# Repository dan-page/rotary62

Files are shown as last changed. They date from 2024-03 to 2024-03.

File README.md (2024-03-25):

# rotary62
ISO 65% Keyboard with Integrated Plate and Rotary Encoder

Includes:
- Case 
- Base
- PCB
- Silicone Sound Dampener
- Encoder Knob
- Rubber Feet

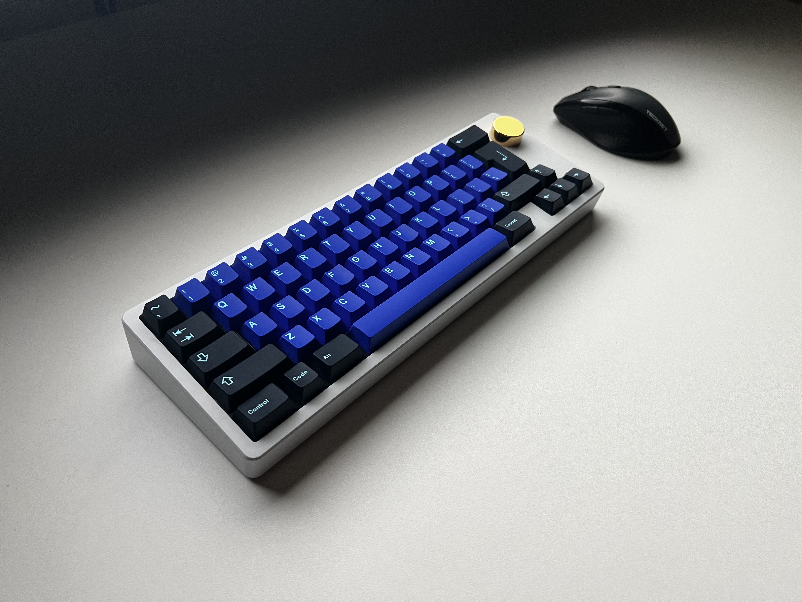
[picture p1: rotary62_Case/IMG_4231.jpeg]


## Case
Machined out of 6063 Aluminium and finished in E-White

## Base
Machined out of 6063 Aluminium and anodised black.

## PCB
The PCB was designed to use common components from JLCPCB. Firmware is available from the [QMK Repo](https://github.com/qmk/qmk_firmware).

## Silicone Sound Dampener
This includes a 3D printable mould that can be filled with silicone to create a sound dampener for inside the case. After 3D printing the two parts of the mould need glueing together and the seam between the two parts making smooth through sanding and filler. 

## Encoder Knob
Machined out of Brass and polished.

## Rubber Feet
Cut from a strip of adhesive-backed 60SH Black Silicone and stuck to the recessed gaps on the base.

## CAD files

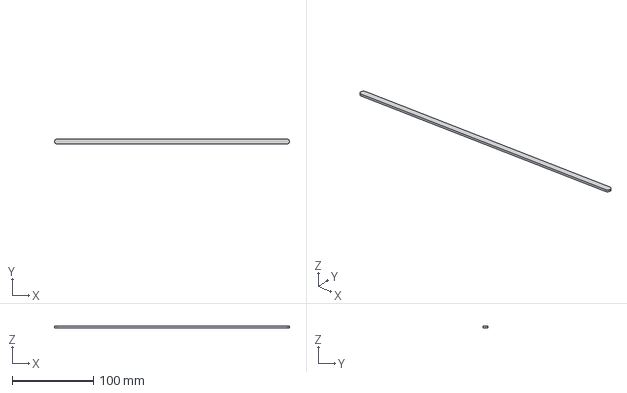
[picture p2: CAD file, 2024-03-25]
rotary62_Case/Rubber Strip.step
289.8 x 6.30 x 2.00 mm

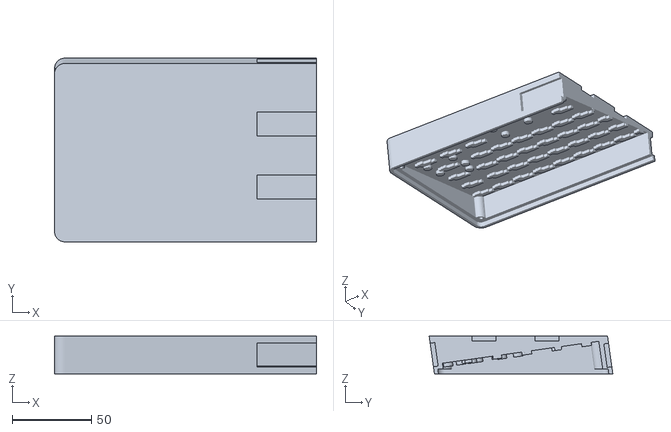
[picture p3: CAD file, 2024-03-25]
rotary62_Dampener/Mold2.stl
165.3 x 115.9 x 23.7

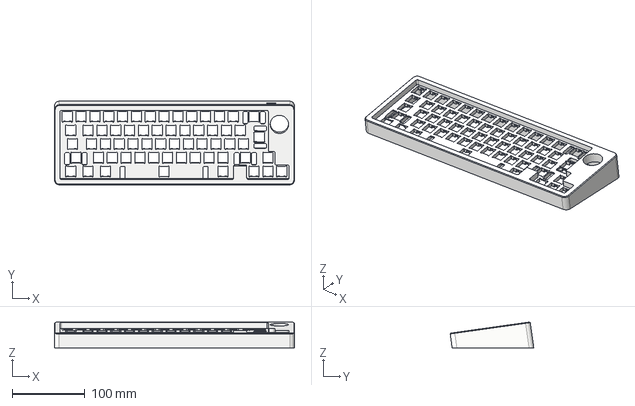
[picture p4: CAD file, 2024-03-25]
rotary62_Case/CaseTop.step
330.5 x 115.2 x 35.7 mm

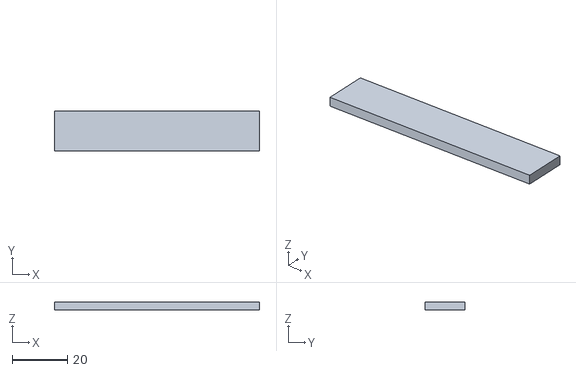
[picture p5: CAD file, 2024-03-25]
rotary62_Dampener/MoldLatch.stl
74.5 x 14.5 x 3.00

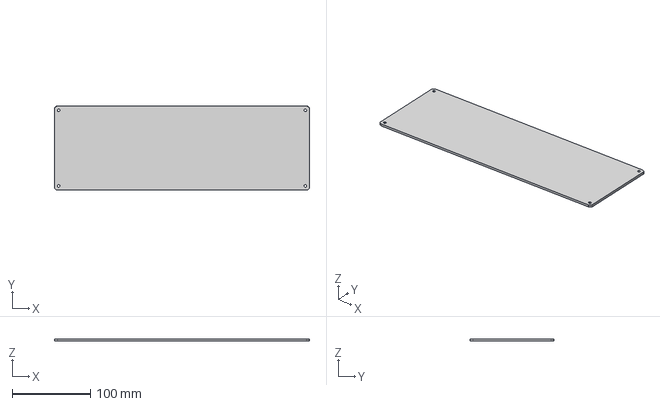
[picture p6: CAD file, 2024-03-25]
rotary62_Case/CaseBase.step
324.9 x 107.3 x 3.13 mm

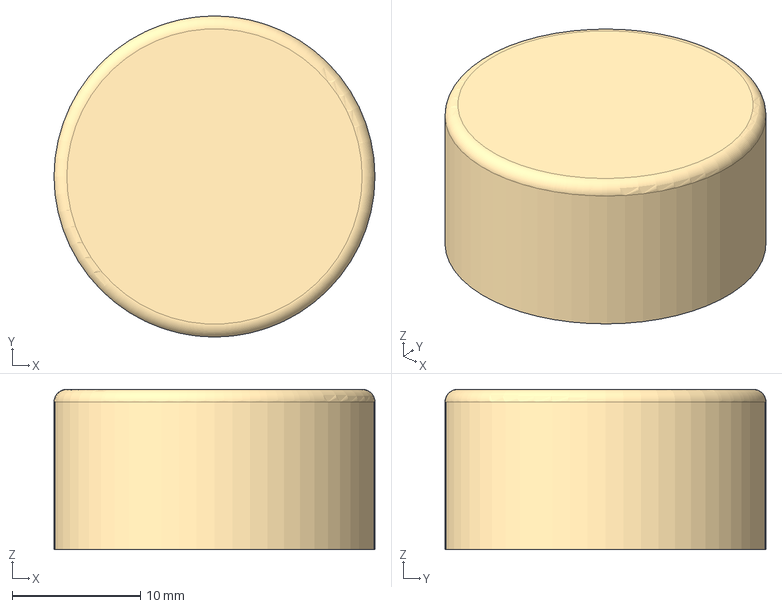
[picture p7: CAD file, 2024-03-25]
rotary62_Case/EncoderKnob.step
25.0 x 25.0 x 12.5 mm

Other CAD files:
rotary62_Dampener/mold1.stl

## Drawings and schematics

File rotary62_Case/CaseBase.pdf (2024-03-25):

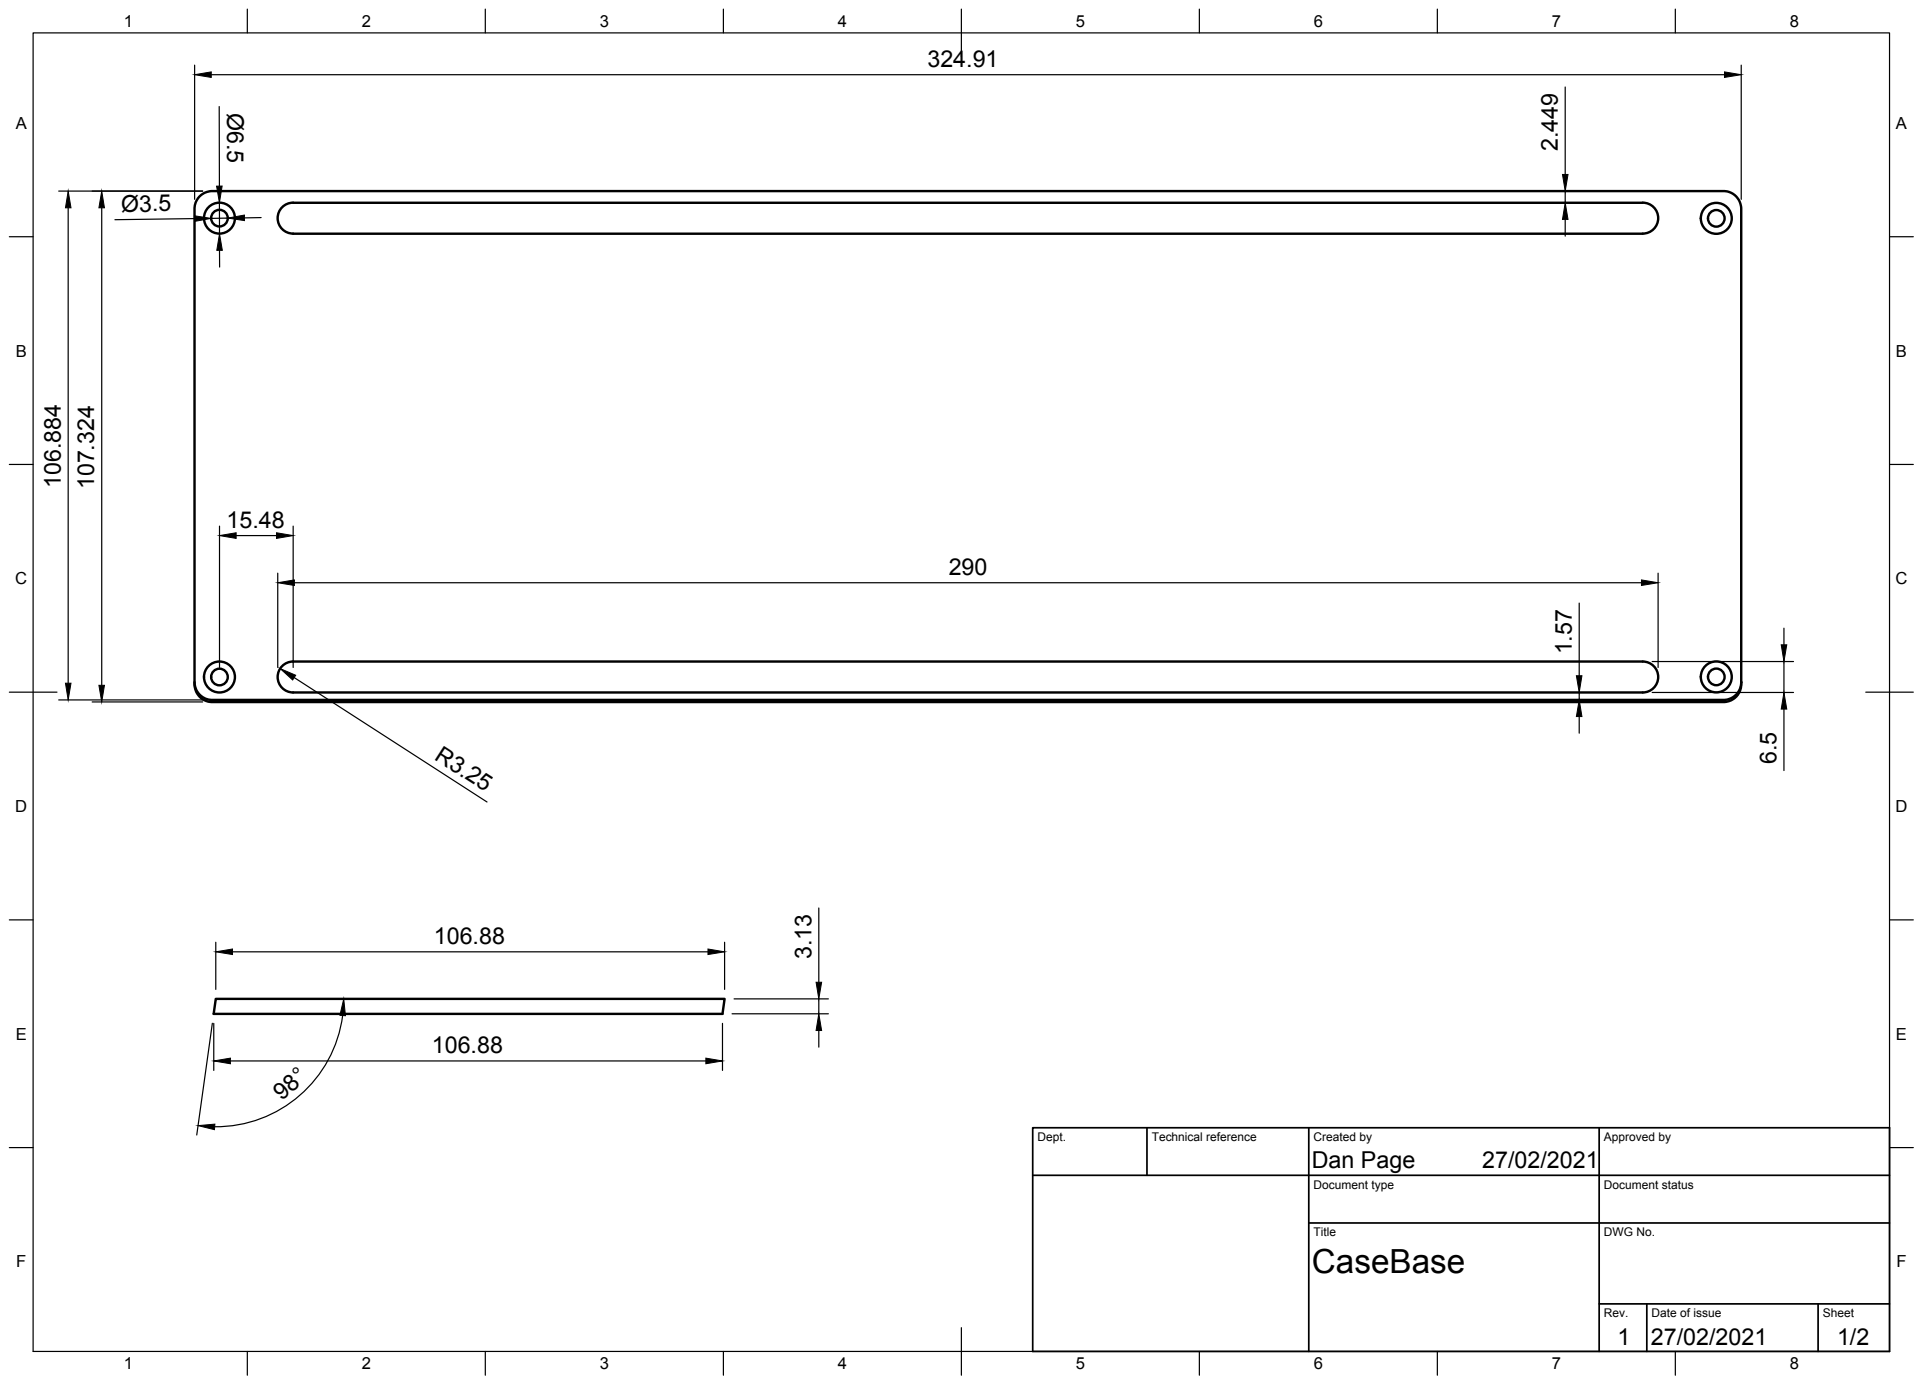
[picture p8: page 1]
Title; DWG No.; Rev.; Date of issue; Sheet

Dept. | Technical reference | Created by Dan Page 27/02/2021 | Approved by

Document type | Document status

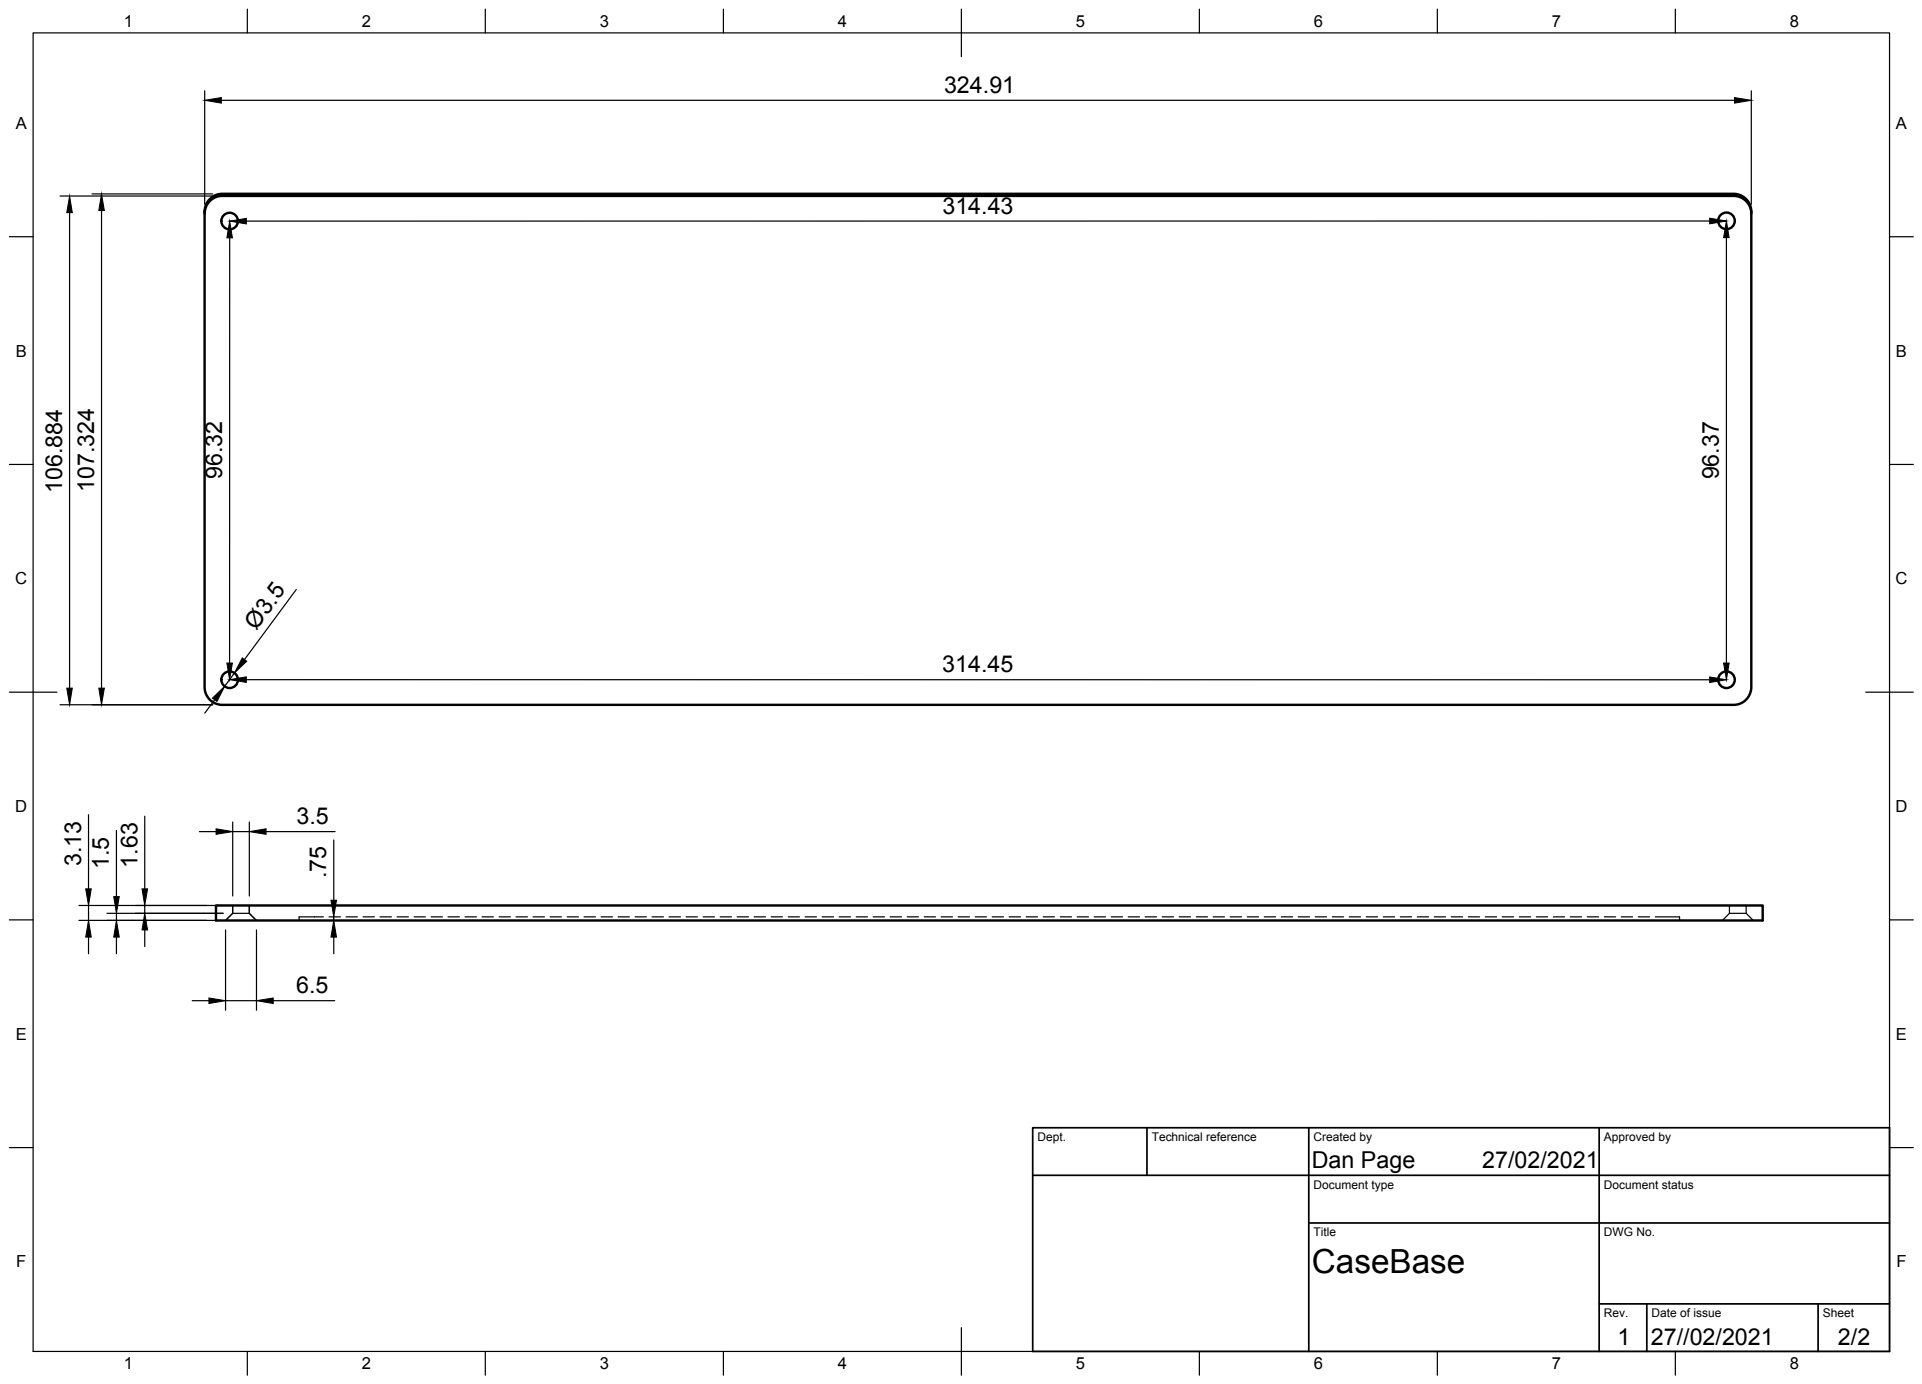
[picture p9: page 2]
Title; DWG No.; Rev.; Date of issue; Sheet

Dept. | Technical reference | Created by Dan Page 27/02/2021 | Approved by

Document type | Document status

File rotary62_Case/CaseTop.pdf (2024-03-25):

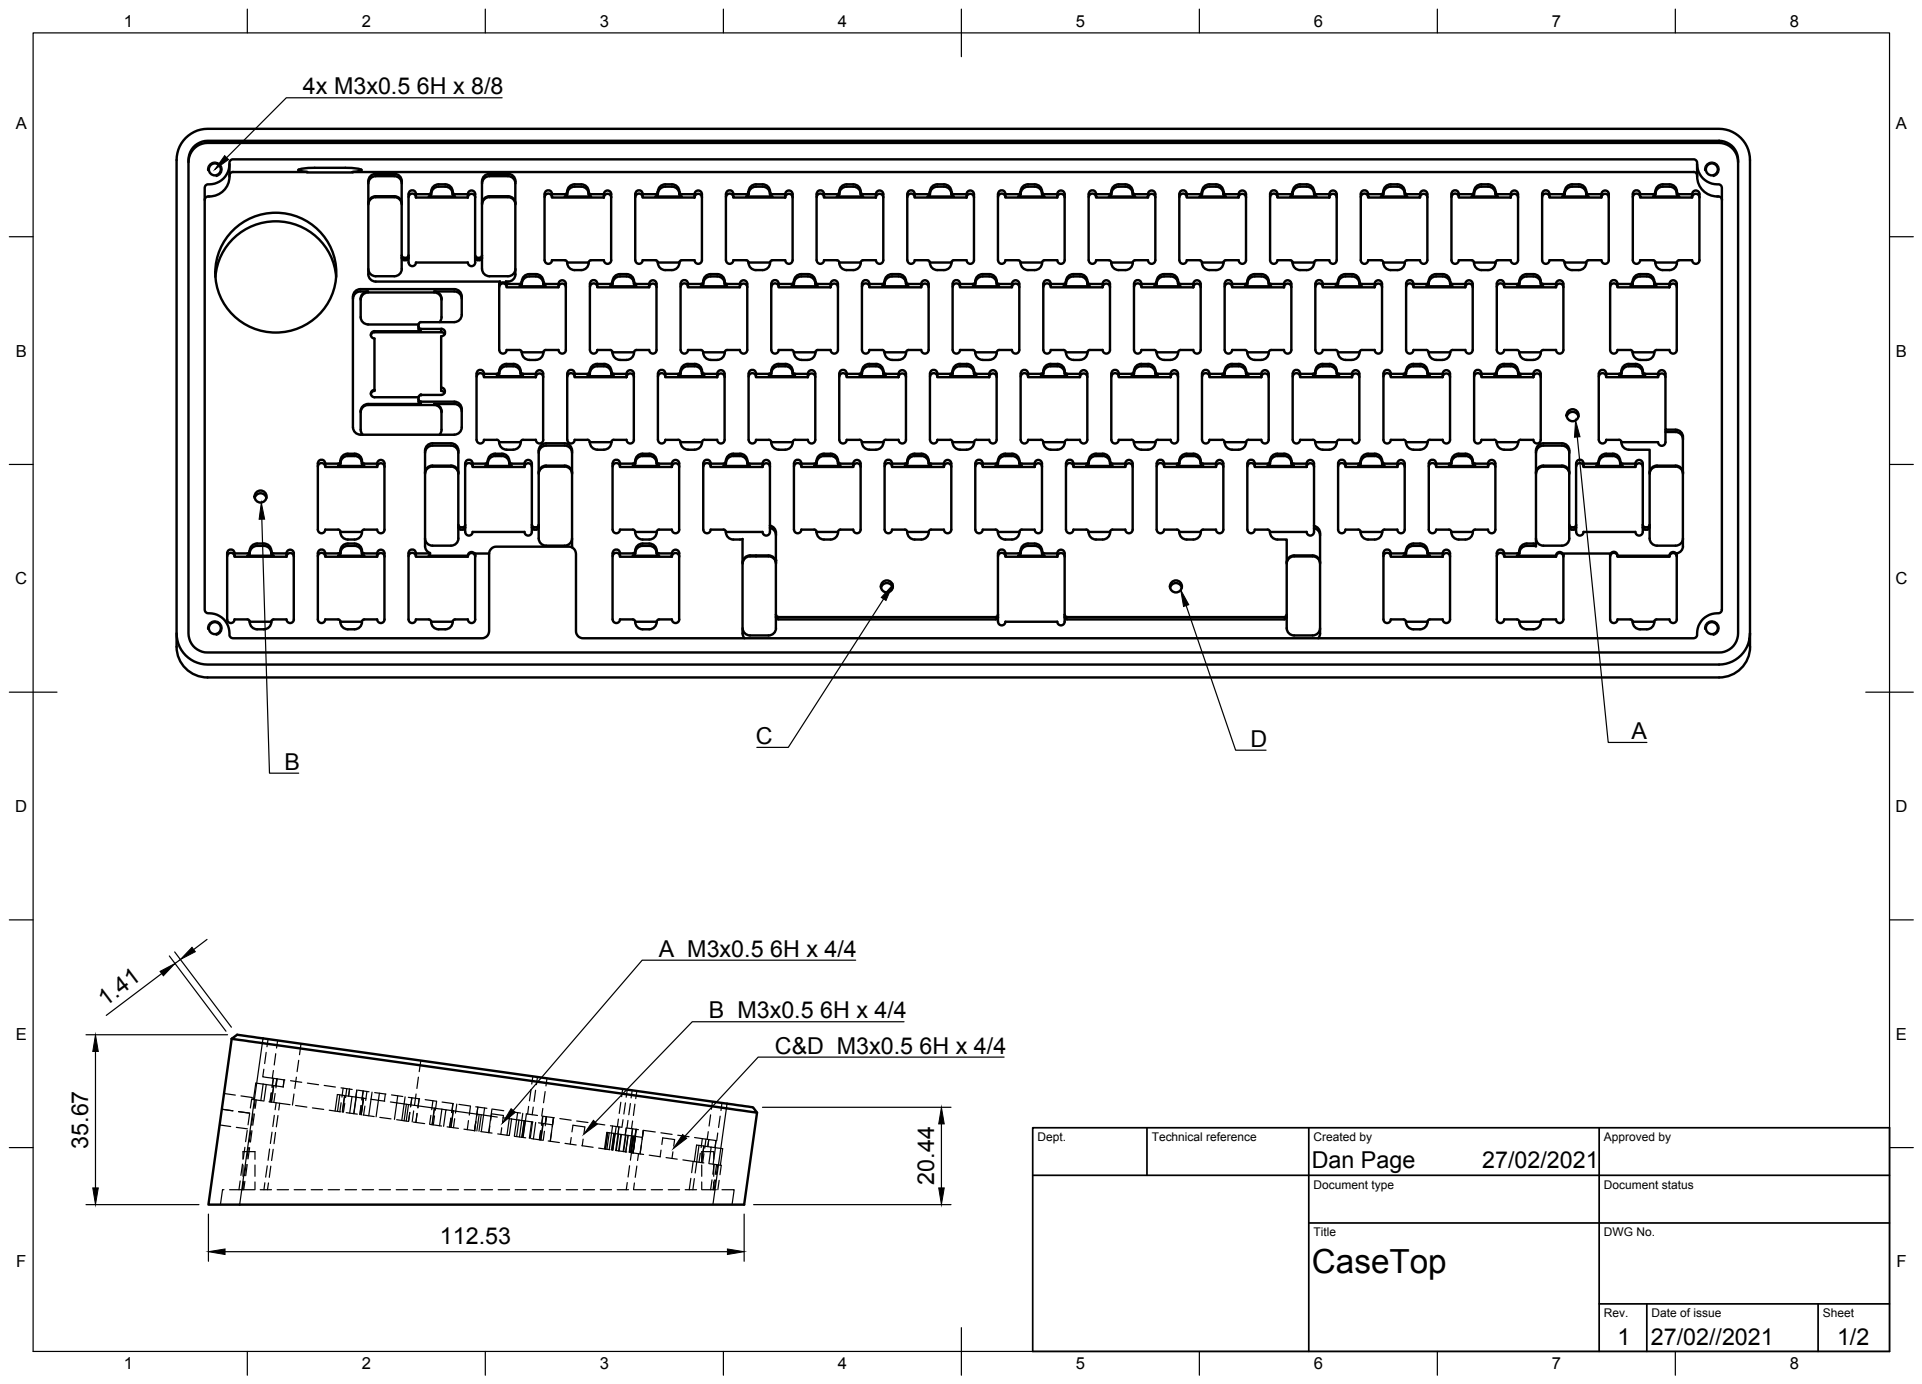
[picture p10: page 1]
Title; DWG No.; Rev.; Date of issue; Sheet

Dept. | Technical reference | Created by Dan Page 27/02/2021 | Approved by

Document type | Document status

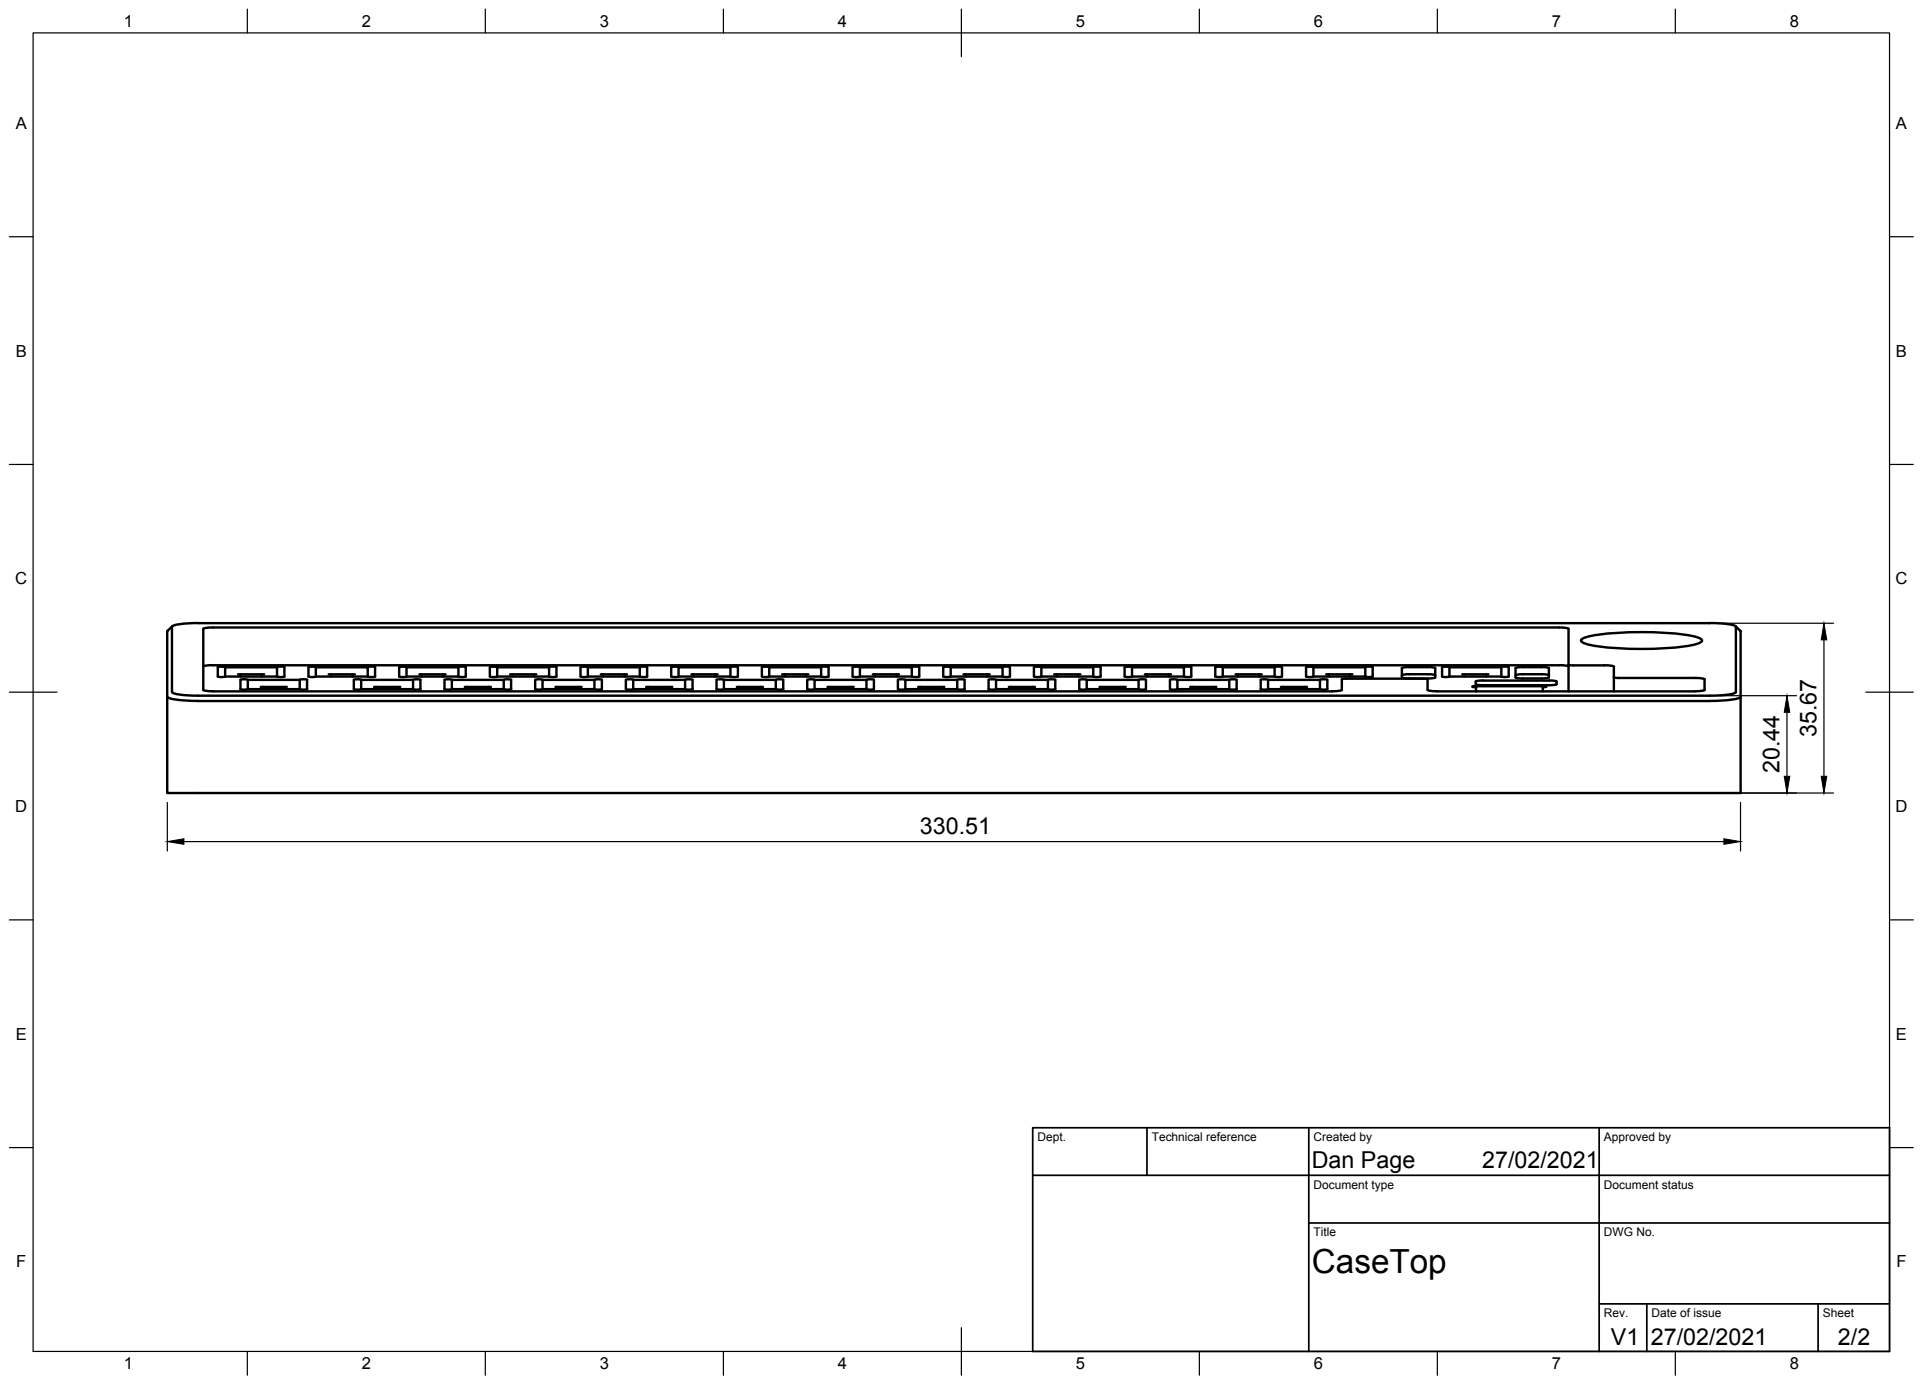
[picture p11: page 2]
Title; DWG No.; Rev.; Date of issue; Sheet; Dan Page

Dept. | Technical reference | Created by 27/02/2021 | Approved by

Document type | Document status

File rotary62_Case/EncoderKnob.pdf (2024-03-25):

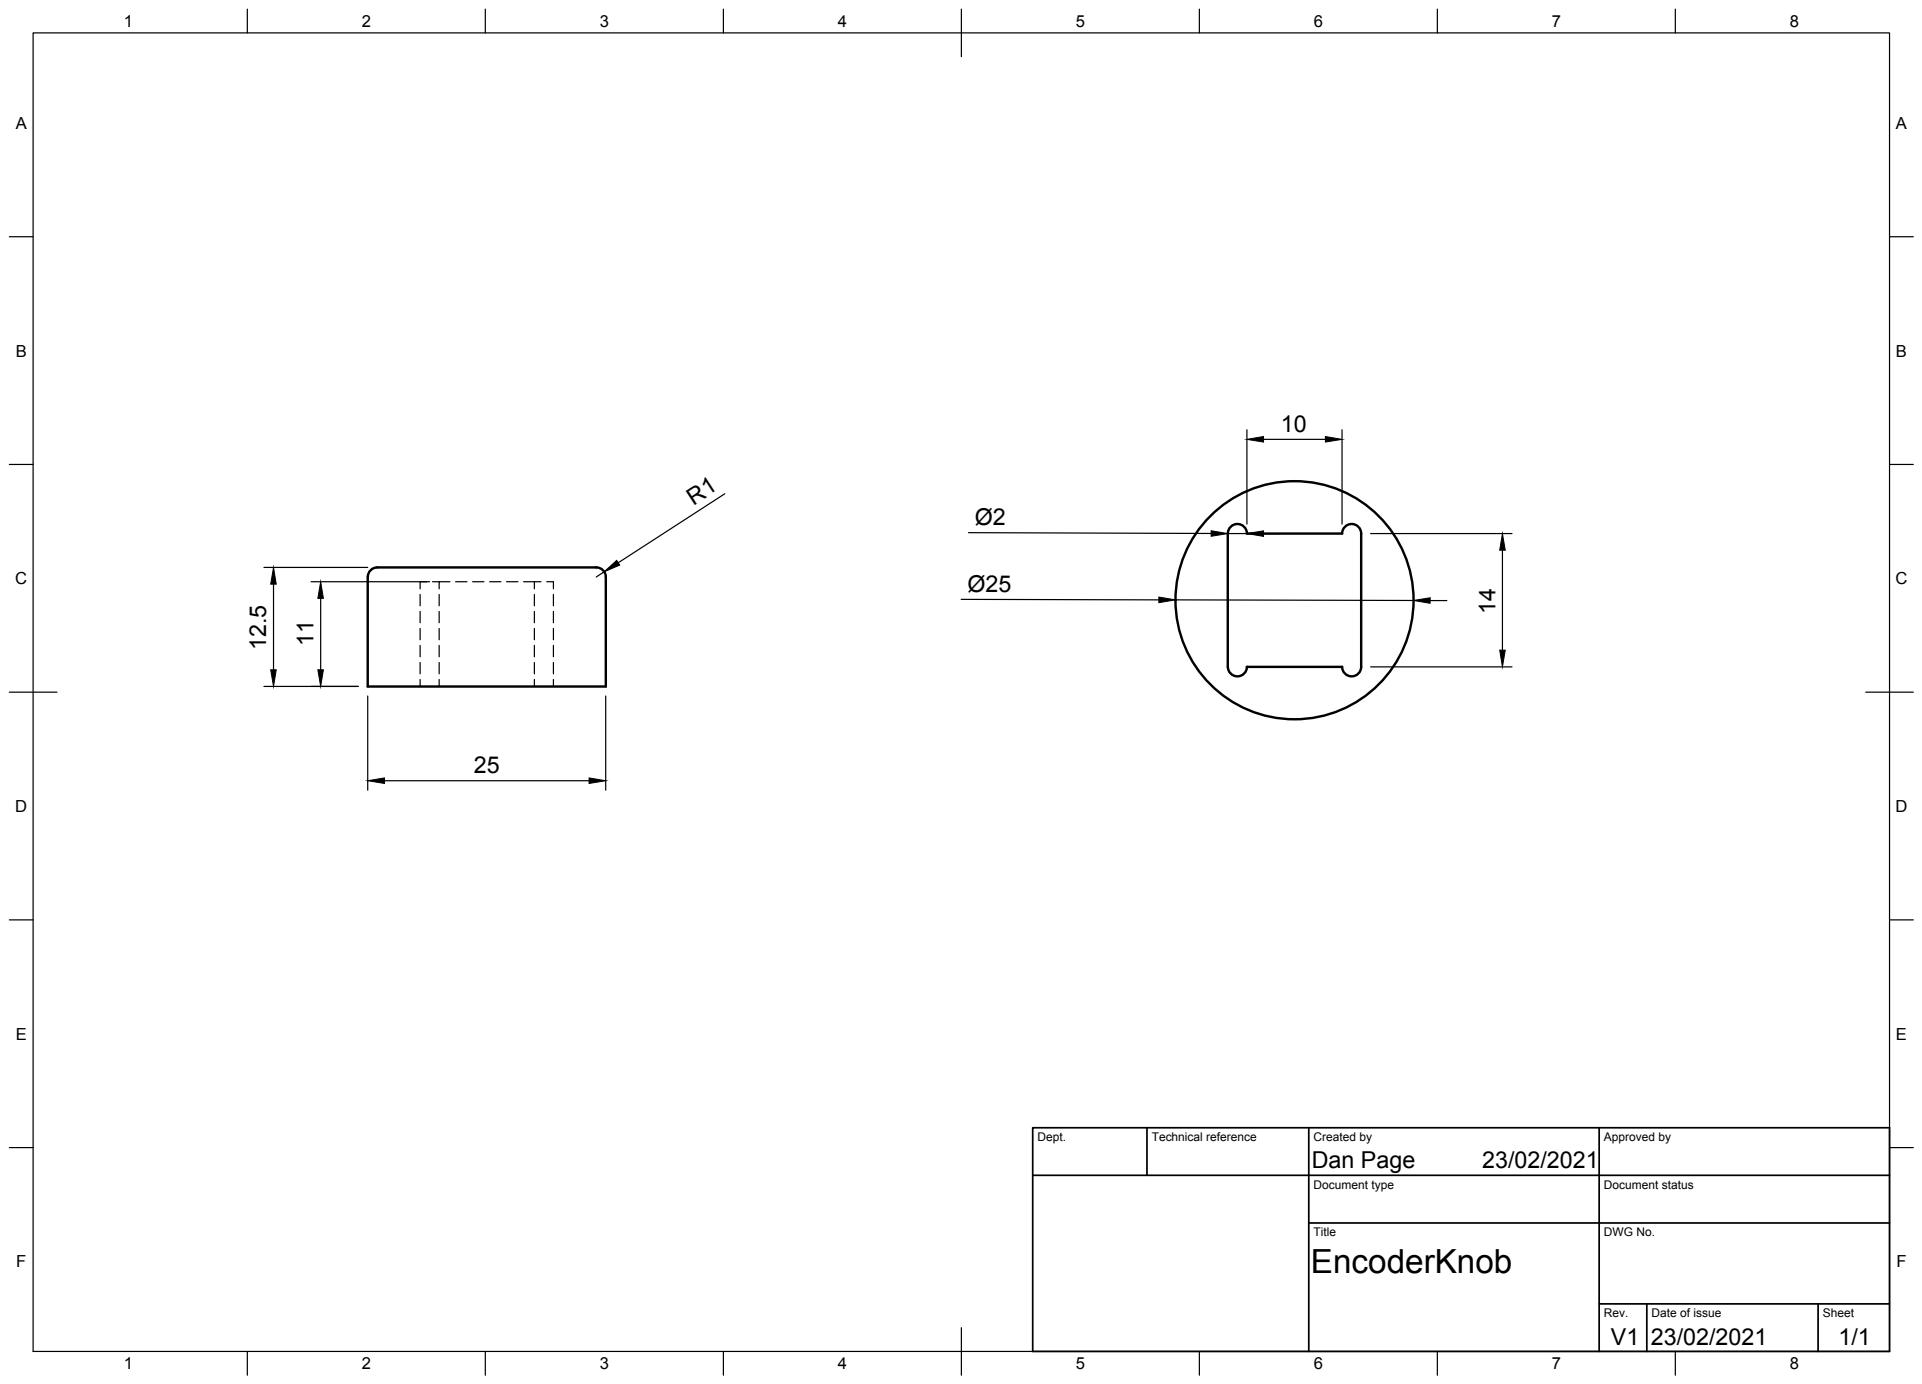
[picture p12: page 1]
Title; DWG No.; Rev.; Date of issue; Sheet; Dan Page 12.5

Dept. | Technical reference | Created by 23/02/2021 | Approved by

Document type | Document status

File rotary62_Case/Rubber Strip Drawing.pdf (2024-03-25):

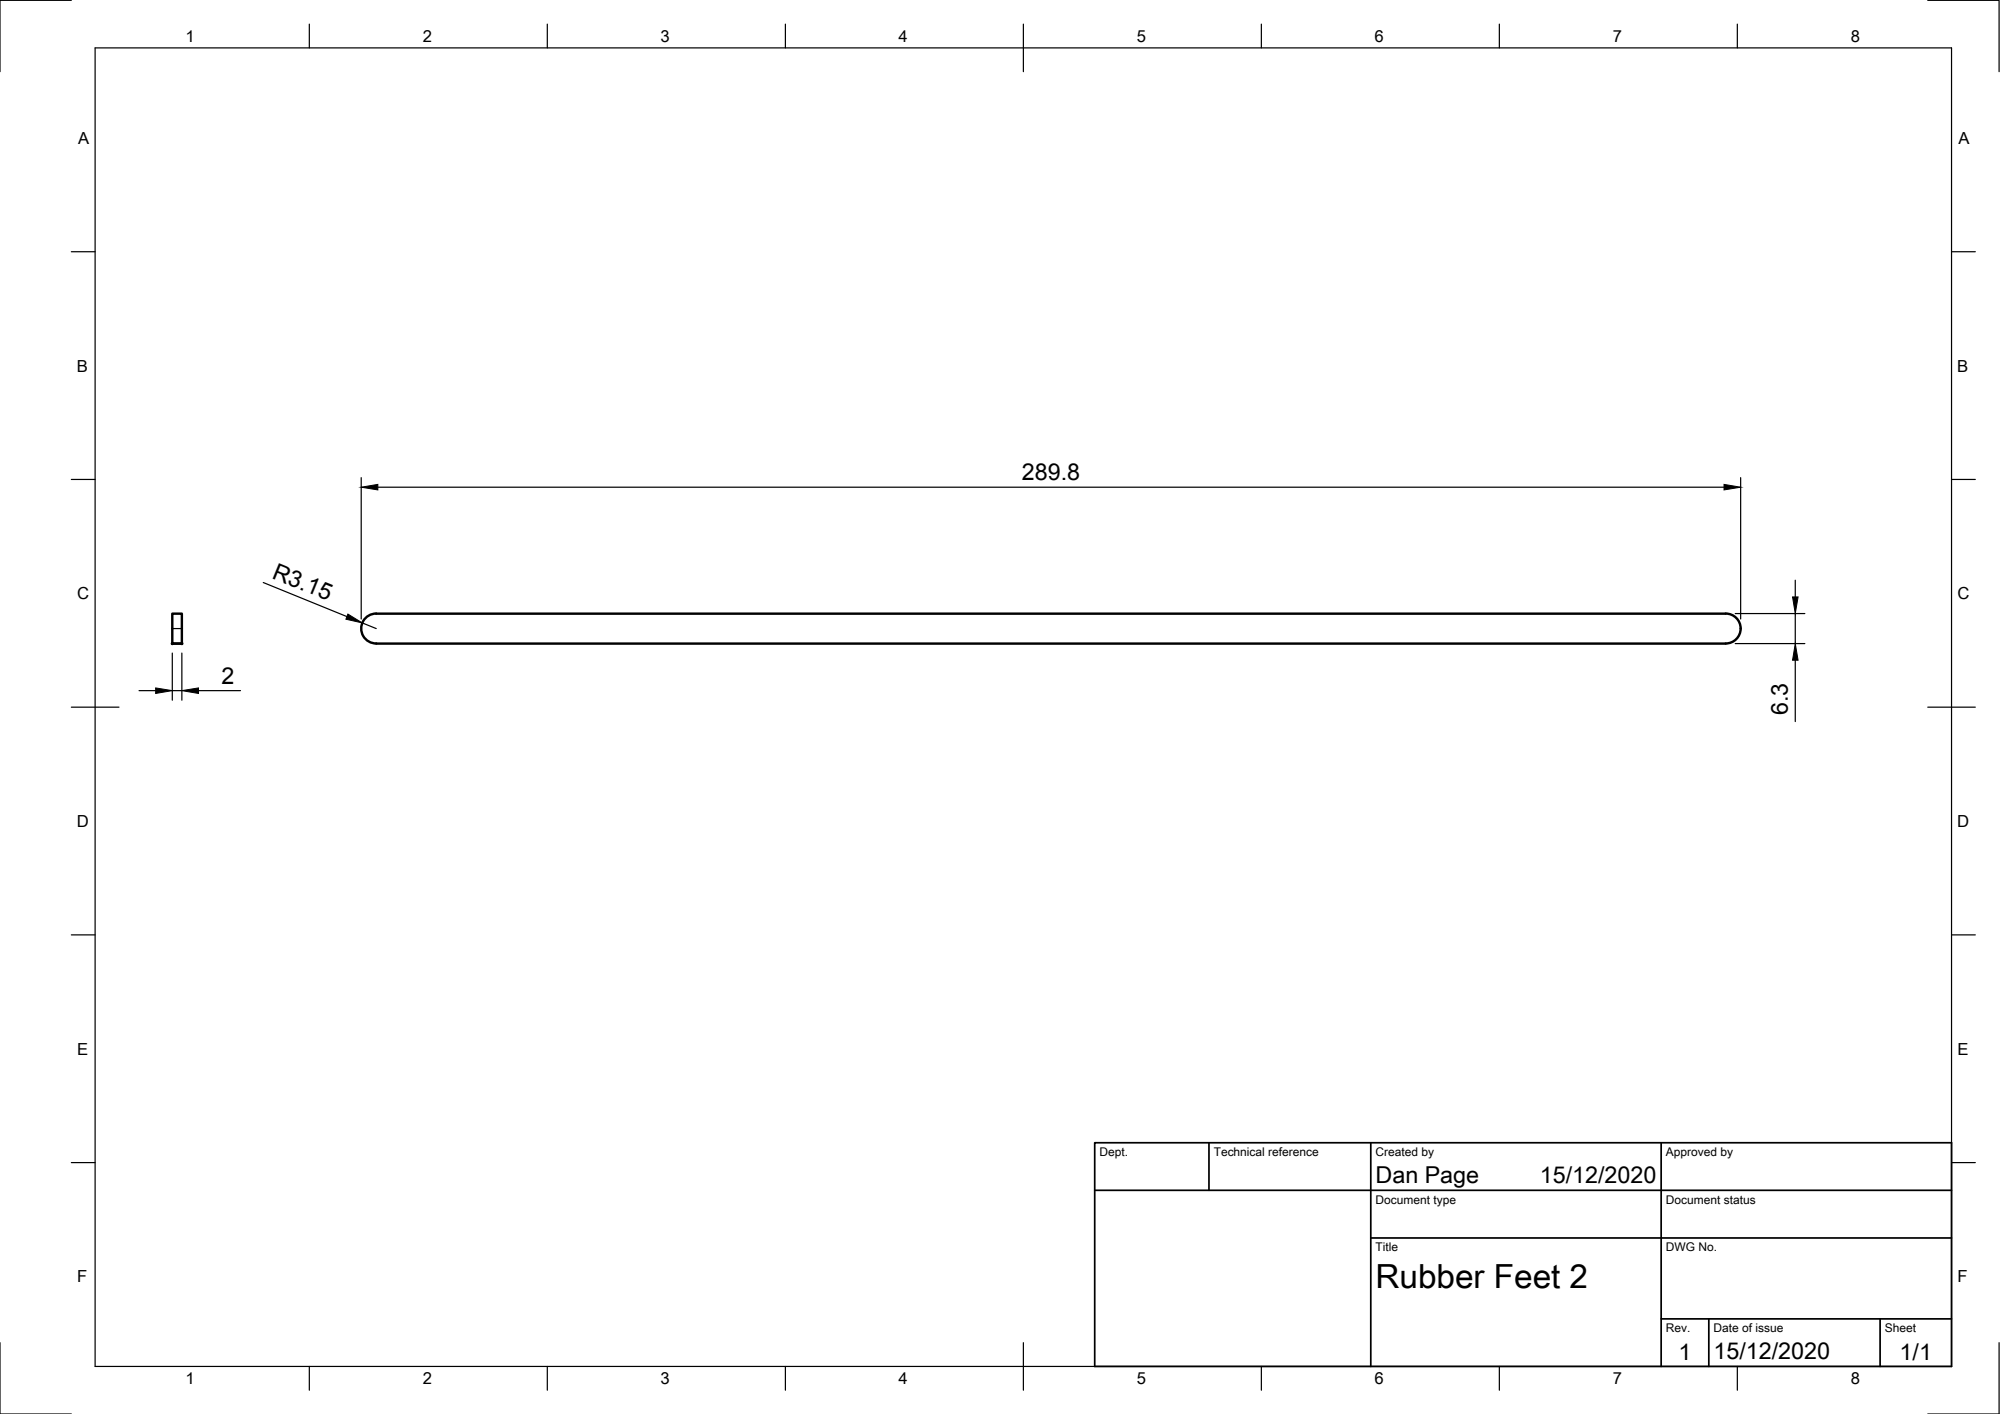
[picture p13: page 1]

Dept. | Technical reference | Created by Dan Page 15/12/2020 | Approved by

Document type | Document status

Title Rubber Feet 2 | DWG No.

Rev. 1 | Date of issue 15/12/2020 | Sheet 1/1

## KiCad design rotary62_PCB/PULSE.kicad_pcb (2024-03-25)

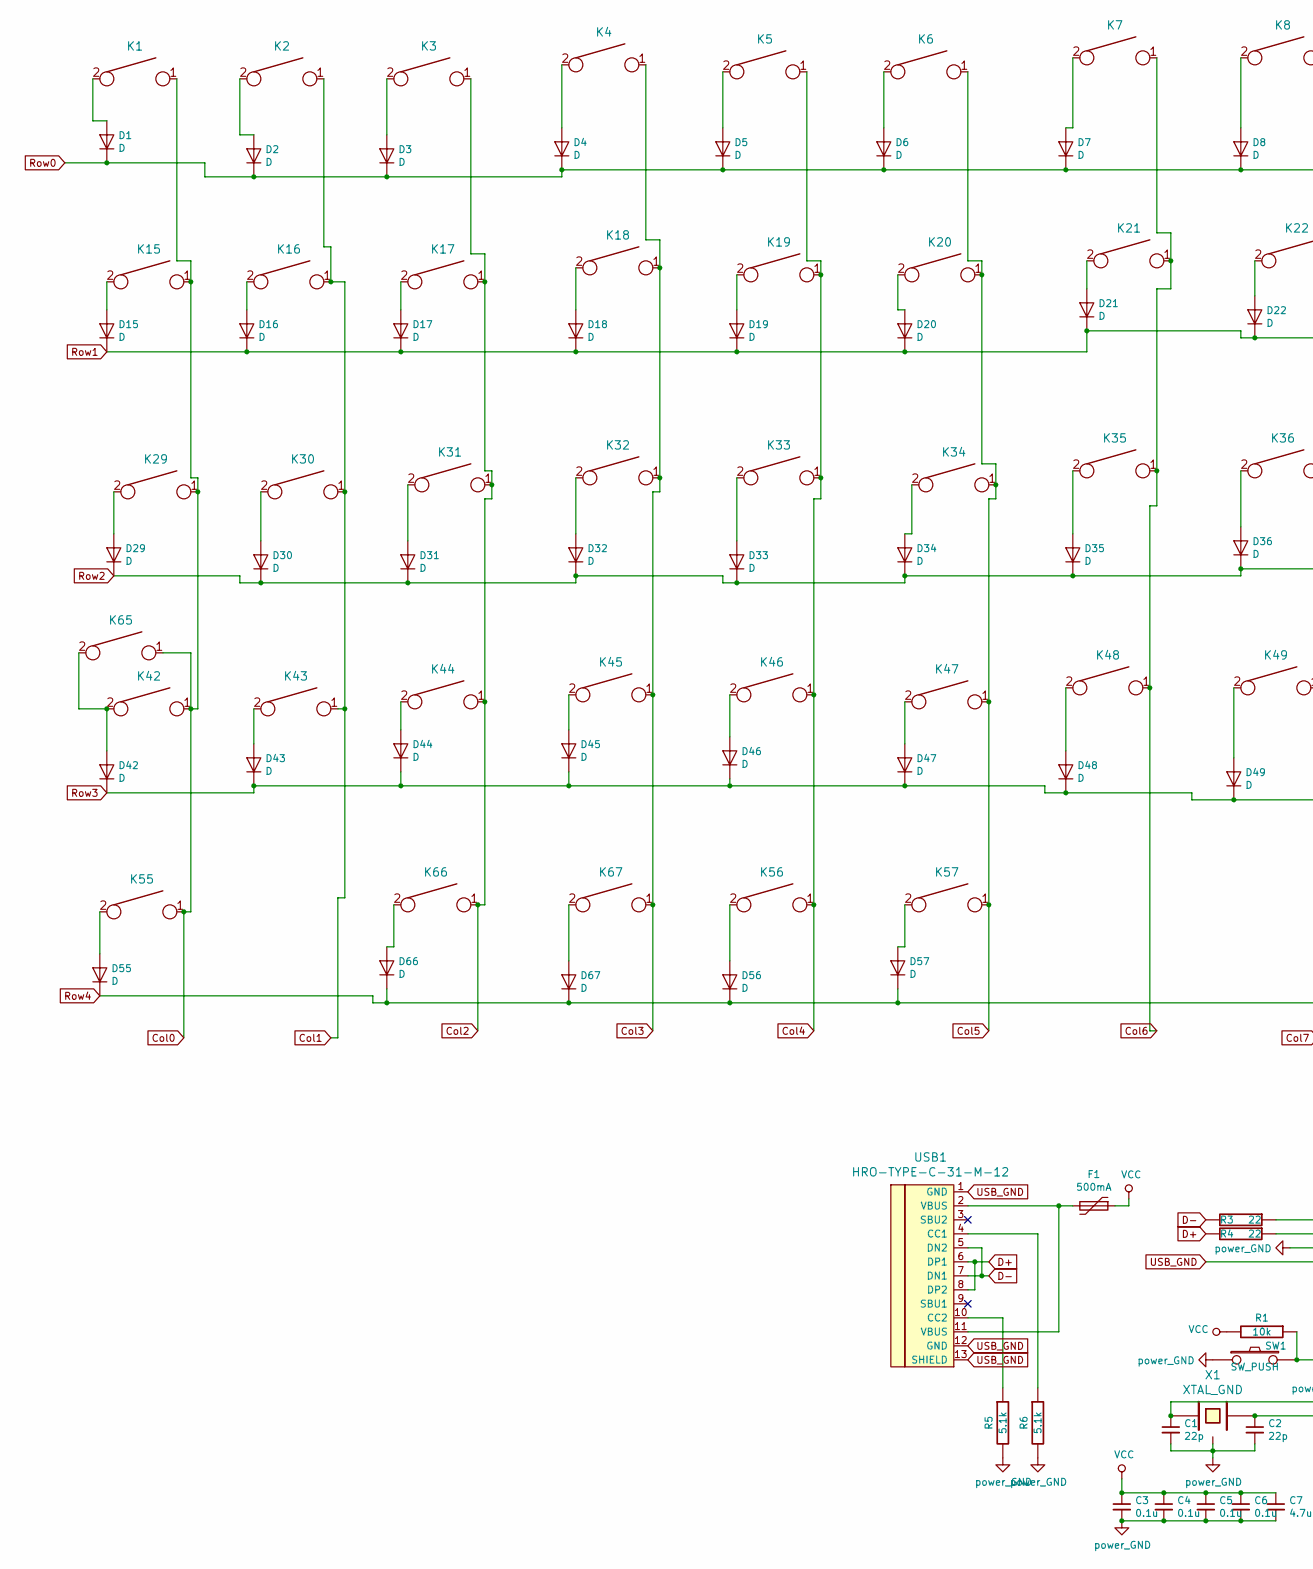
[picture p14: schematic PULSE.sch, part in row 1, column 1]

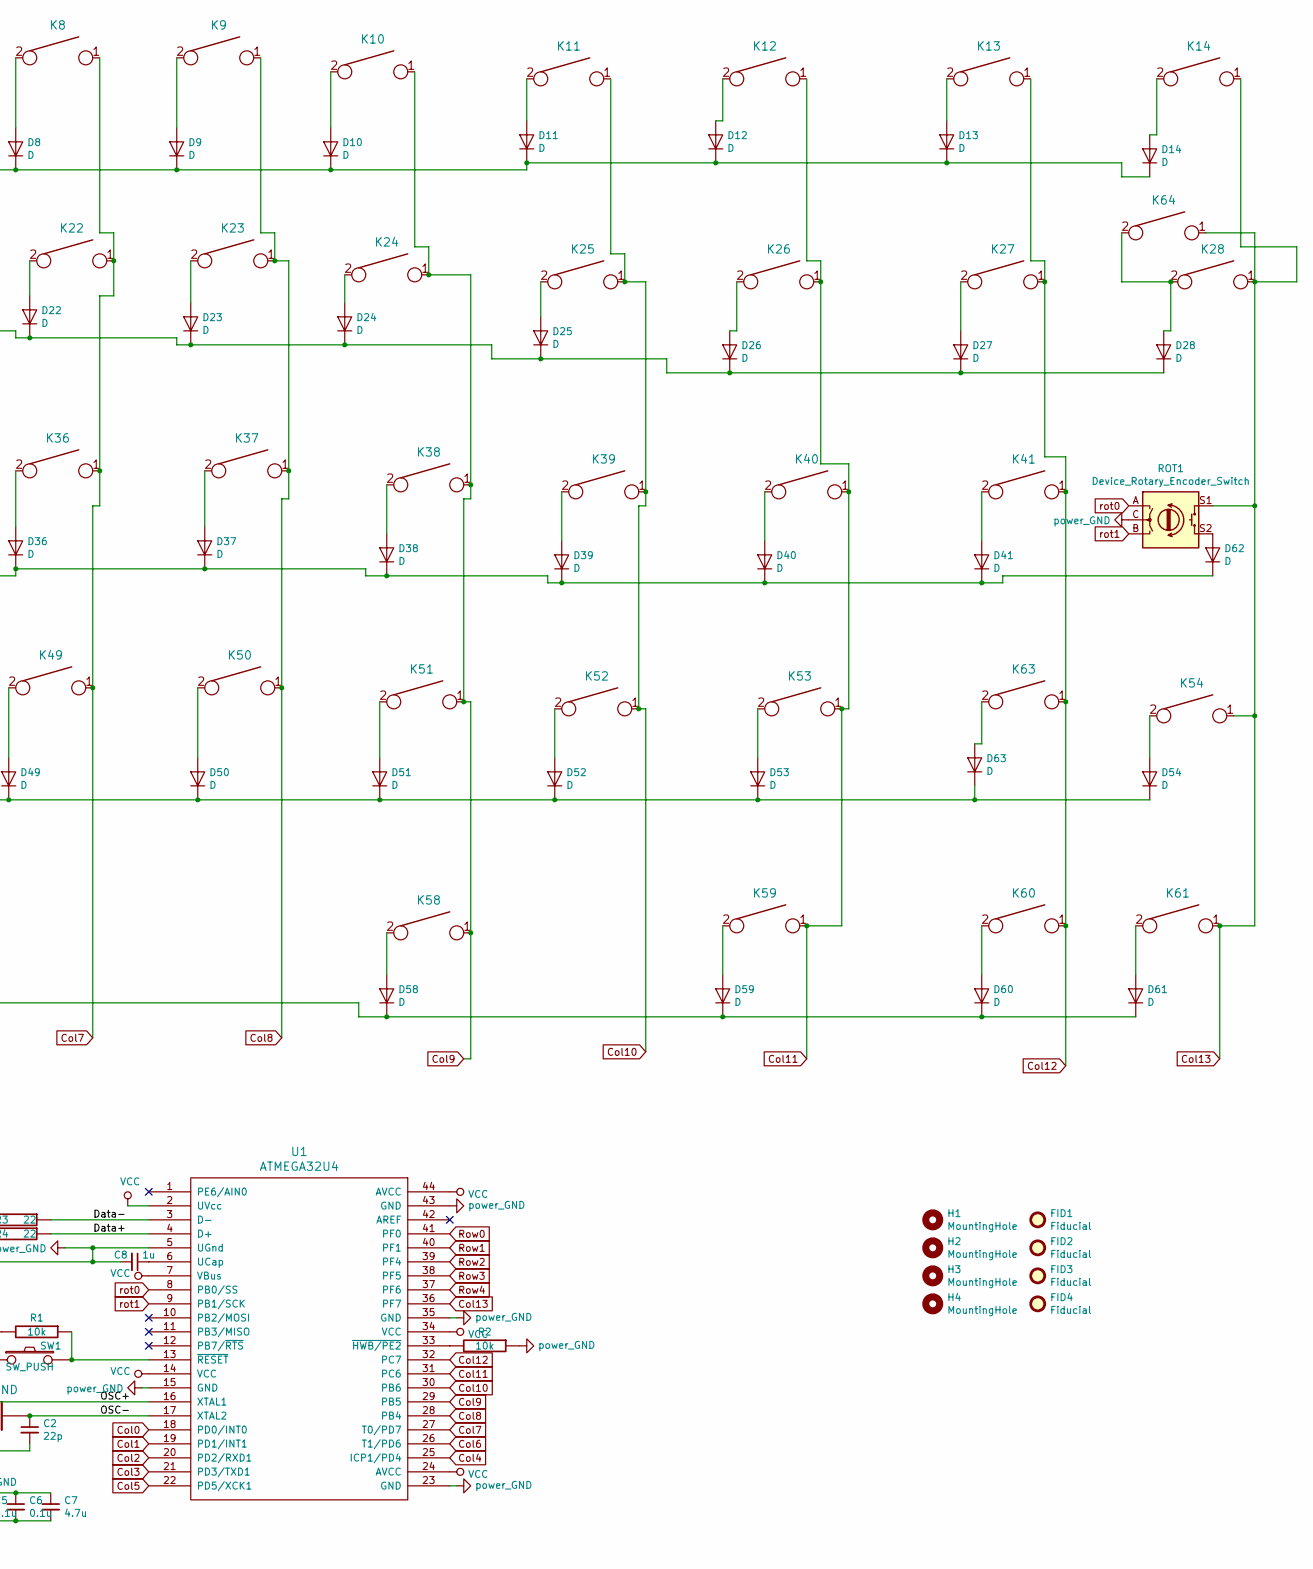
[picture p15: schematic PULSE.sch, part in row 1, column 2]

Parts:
C1, C2: 22p; C_0805_HandSoldering
C3, C4, C5, C6: 0.1u; C_0805_HandSoldering
C7: 4.7u; C_0805_HandSoldering
C8: 1u; C_0805_HandSoldering
D1, D2, D3, D4, D5, D6, D7, D8, D9, D10, D11, D12, D13, D14, D15, D16, D17, D18, D19, D20, D21, D22, D23, D24, D25, D26, D27, D28, D29, D30, D31, D32, D33, D34, D35, D36, D37, D38, D39, D40, D41, D42, D43, D44, D45, D46, D47, D48, D49, D50, D51, D52, D53, D54, D55, D56, D57, D58, D59, D60, D61, D62, D63, D66, D67: D; D_SOD123_handD
F1: 500mA; C_1206_HandSoldering
FID1, FID2, FID3, FID4: Fiducial; Fiducial_1mm_Dia_2mm_Outer
H1, H2, H3, H4: MountingHole; MountingHole_3.5mm_Pad
K1, K2, K3, K4, K5, K6, K7, K8, K9, K10, K11, K12, K13, K16, K17, K18, K19, K20, K21, K22, K23, K24, K25, K26, K27, K30, K31, K32, K33, K34, K35, K36, K37, K38, K39, K40, K43, K44, K45, K46, K47, K48, K49, K50, K51, K52, K54, K59, K60, K61, K67: KEYSW; MXOnly-1U-Hotswap
K14: KEYSW; MXOnly-2U-Hotswap
K15, K55, K56, K58, K63: KEYSW; MXOnly-1.5U-Hotswap
K28: KEYSW; ISO_Hotswap
K29: KEYSW; MXOnly-1.75U-Hotswap
K41: KEYSW; 1U 2 up
K42: KEYSW; 2.25U 2 up
K53: KEYSW; MXOnly-2.25U-Hotswap
K57: KEYSW; MXOnly-7U-Hotswap
K64: KEYSW; 2.25u 1u down
K65: KEYSW; MXOnly-1.25U-Hotswap
K66: KEYSW; 1U 1 down
R1, R2: 10k; R_0805_HandSoldering
R3, R4: 22; R_0805_HandSoldering
R5, R6: 5.1k; R_0805_HandSoldering
ROT1: Device_Rotary_Encoder_Switch; RotaryEncoder_Alps_EC11E-Switch_Vertical_H20mm
SW1: SW_PUSH; SW_SPST_TL3342
U1: ATMEGA32U4; TQFP-44_10x10mm_Pitch0.8mm
USB1: HRO-TYPE-C-31-M-12; HRO-TYPE-C-31-M-12-HandSoldering
X1: XTAL_GND; FA-238

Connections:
/Data+: R4.1, U1.4 (D+)
/Data-: R3.1, U1.3 (D-)
/OSC+: C1.1, U1.16 (XTAL1), X1.1
/OSC-: C2.1, U1.17 (XTAL2), X1.2
Col0: K1.1, K15.1, K29.1, K42.1, K55.1, K65.1, U1.18 (PD0/INT0)
Col1: K2.1, K16.1, K30.1, K43.1, U1.19 (PD1/INT1)
Col2: K3.1, K17.1, K31.1, K44.1, K66.1, U1.20 (PD2/RXD1)
Col3: K4.1, K18.1, K32.1, K45.1, K67.1, U1.21 (PD3/TXD1)
Col4: K5.1, K19.1, K33.1, K46.1, K56.1, U1.25 (ICP1/PD4)
Col5: K6.1, K20.1, K34.1, K47.1, K57.1, U1.22 (PD5/XCK1)
Col6: K7.1, K21.1, K35.1, K48.1, U1.26 (T1/PD6)
Col7: K8.1, K22.1, K36.1, K49.1, U1.27 (T0/PD7)
Col8: K9.1, K23.1, K37.1, K50.1, U1.28 (PB4)
Col9: K10.1, K24.1, K38.1, K51.1, K58.1, U1.29 (PB5)
Col10: K11.1, K25.1, K39.1, K52.1, U1.30 (PB6)
Col11: K12.1, K26.1, K40.1, K53.1, K59.1, U1.31 (PC6)
Col12: K13.1, K27.1, K41.1, K60.1, K63.1, U1.32 (PC7)
Col13: K14.1, K28.1, K54.1, K61.1, K64.1, ROT1.S1, U1.36 (PF7)
D+: R4.2, USB1.6 (DP1), USB1.8 (DP2)
D-: R3.2, USB1.5 (DN2), USB1.7 (DN1)
unnamed: C8.1, U1.6 (UCap)
unnamed: D1.2 (A), K1.2
unnamed: D2.2 (A), K2.2
unnamed: D3.2 (A), K3.2
unnamed: D4.2 (A), K4.2
unnamed: D5.2 (A), K5.2
unnamed: D6.2 (A), K6.2
unnamed: D7.2 (A), K7.2
unnamed: D8.2 (A), K8.2
unnamed: D9.2 (A), K9.2
unnamed: D10.2 (A), K10.2
unnamed: D11.2 (A), K11.2
unnamed: D12.2 (A), K12.2
unnamed: D13.2 (A), K13.2
unnamed: D14.2 (A), K14.2
unnamed: D15.2 (A), K15.2
unnamed: D16.2 (A), K16.2
unnamed: D17.2 (A), K17.2
unnamed: D18.2 (A), K18.2
unnamed: D19.2 (A), K19.2
unnamed: D20.2 (A), K20.2
unnamed: D21.2 (A), K21.2
unnamed: D22.2 (A), K22.2
unnamed: D23.2 (A), K23.2
unnamed: D24.2 (A), K24.2
unnamed: D25.2 (A), K25.2
unnamed: D26.2 (A), K26.2
unnamed: D27.2 (A), K27.2
unnamed: D28.2 (A), K28.2, K64.2
unnamed: D29.2 (A), K29.2
unnamed: D30.2 (A), K30.2
unnamed: D31.2 (A), K31.2
unnamed: D32.2 (A), K32.2
unnamed: D33.2 (A), K33.2
unnamed: D34.2 (A), K34.2
unnamed: D35.2 (A), K35.2
unnamed: D36.2 (A), K36.2
unnamed: D37.2 (A), K37.2
unnamed: D38.2 (A), K38.2
unnamed: D39.2 (A), K39.2
unnamed: D40.2 (A), K40.2
unnamed: D41.2 (A), K41.2
unnamed: D42.2 (A), K42.2, K65.2
unnamed: D43.2 (A), K43.2
unnamed: D44.2 (A), K44.2
unnamed: D45.2 (A), K45.2
unnamed: D46.2 (A), K46.2
unnamed: D47.2 (A), K47.2
unnamed: D48.2 (A), K48.2
unnamed: D49.2 (A), K49.2
unnamed: D50.2 (A), K50.2
unnamed: D51.2 (A), K51.2
unnamed: D52.2 (A), K52.2
unnamed: D53.2 (A), K53.2
unnamed: D54.2 (A), K54.2
unnamed: D55.2 (A), K55.2
unnamed: D56.2 (A), K56.2
unnamed: D57.2 (A), K57.2
unnamed: D58.2 (A), K58.2
unnamed: D59.2 (A), K59.2
unnamed: D60.2 (A), K60.2
unnamed: D61.2 (A), K61.2
unnamed: D62.2 (A), ROT1.S2
unnamed: D63.2 (A), K63.2
unnamed: D66.2 (A), K66.2
unnamed: D67.2 (A), K67.2
unnamed: F1.2, USB1.2 (VBUS), USB1.11 (VBUS)
unnamed: R1.1, SW1.2, U1.13 (~RESET)
unnamed: R2.2, U1.33 (~HWB/PE2)
unnamed: R5.1, USB1.10 (CC2)
unnamed: R6.1, USB1.4 (CC1)
Row0: D1.1 (K), D2.1 (K), D3.1 (K), D4.1 (K), D5.1 (K), D6.1 (K), D7.1 (K), D8.1 (K), D9.1 (K), D10.1 (K), D11.1 (K), D12.1 (K), D13.1 (K), D14.1 (K), U1.41 (PF0)
Row1: D15.1 (K), D16.1 (K), D17.1 (K), D18.1 (K), D19.1 (K), D20.1 (K), D21.1 (K), D22.1 (K), D23.1 (K), D24.1 (K), D25.1 (K), D26.1 (K), D27.1 (K), D28.1 (K), U1.40 (PF1)
Row2: D29.1 (K), D30.1 (K), D31.1 (K), D32.1 (K), D33.1 (K), D34.1 (K), D35.1 (K), D36.1 (K), D37.1 (K), D38.1 (K), D39.1 (K), D40.1 (K), D41.1 (K), D62.1 (K), U1.39 (PF4)
Row3: D42.1 (K), D43.1 (K), D44.1 (K), D45.1 (K), D46.1 (K), D47.1 (K), D48.1 (K), D49.1 (K), D50.1 (K), D51.1 (K), D52.1 (K), D53.1 (K), D54.1 (K), D63.1 (K), U1.38 (PF5)
Row4: D55.1 (K), D56.1 (K), D57.1 (K), D58.1 (K), D59.1 (K), D60.1 (K), D61.1 (K), D66.1 (K), D67.1 (K), U1.37 (PF6)
USB_GND: C1.2, C2.2, C3.2, C4.2, C5.2, C6.2, C7.2, C8.2, R2.1, R5.2, R6.2, ROT1.C, SW1.1, U1.5 (UGnd), U1.15 (GND), U1.23 (GND), U1.35 (GND), U1.43 (GND), USB1.1 (GND), USB1.12 (GND), USB1.13 (SHIELD), X1.3
VCC: C3.1, C4.1, C5.1, C6.1, C7.1, F1.1, R1.2, U1.2 (UVcc), U1.7 (VBus), U1.14 (VCC), U1.24 (AVCC), U1.34 (VCC), U1.44 (AVCC)
rot0: ROT1.A, U1.8 (PB0/SS)
rot1: ROT1.B, U1.9 (PB1/SCK)

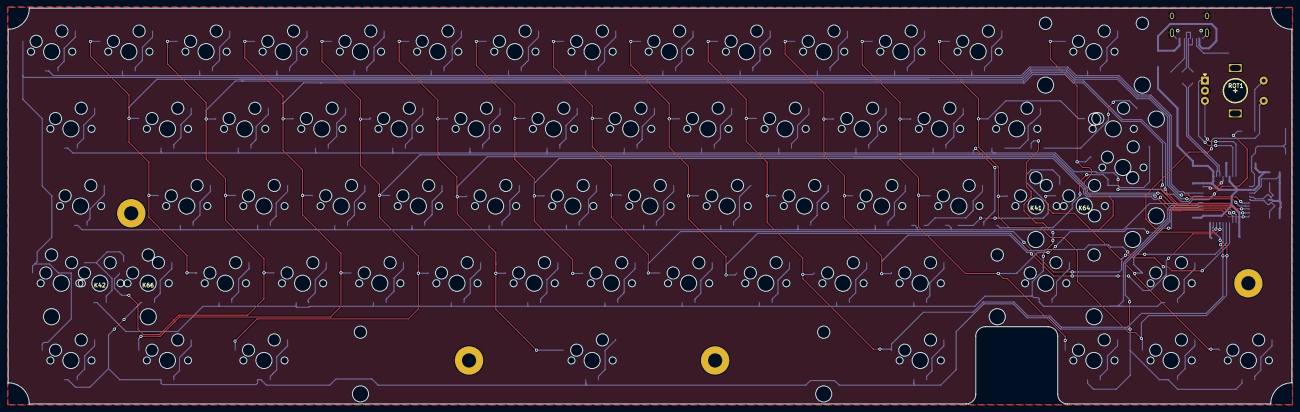
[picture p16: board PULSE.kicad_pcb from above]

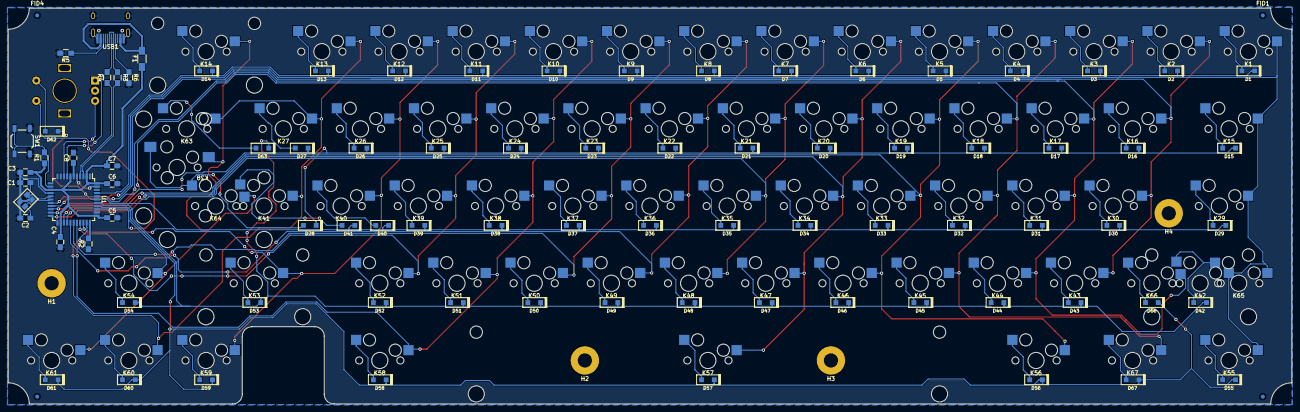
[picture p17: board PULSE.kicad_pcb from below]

Board: 2 copper layers, 316.7 x 97.6 mm, 159 parts (92 on the bottom side), 100 nets.

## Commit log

2024-03-25 Added PCB files for the Rotary62
    [PULSE-B_Cu.gbl, PULSE-B_Mask.gbs, PULSE-B_Paste.gbp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]
2024-03-25 Case files and drawings added
    [CaseBase.step, CaseTop.step, EncoderKnob.step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]
2024-03-25 Added 3D printing files for sound dampener
    [Mold2.stl, MoldLatch.stl, mold1.stl]
